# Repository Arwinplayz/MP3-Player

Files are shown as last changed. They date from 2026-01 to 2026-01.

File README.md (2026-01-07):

# Music Player

## After going camping without reception, I though of creating a mp3 music player which runs off a microSD card. It has WiFi and bluetooth compatibility too!

## Project Overview

The goal was to create a way to listen to music without any reception.

---

## Screenshots

### 1. Overall

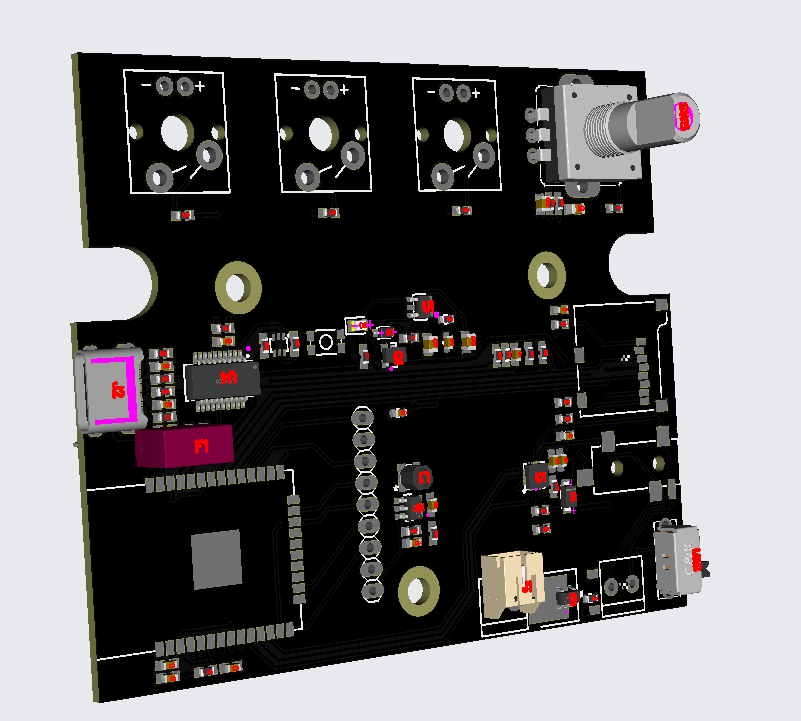
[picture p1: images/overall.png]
Music Player Screenshot


### 2. Schematic

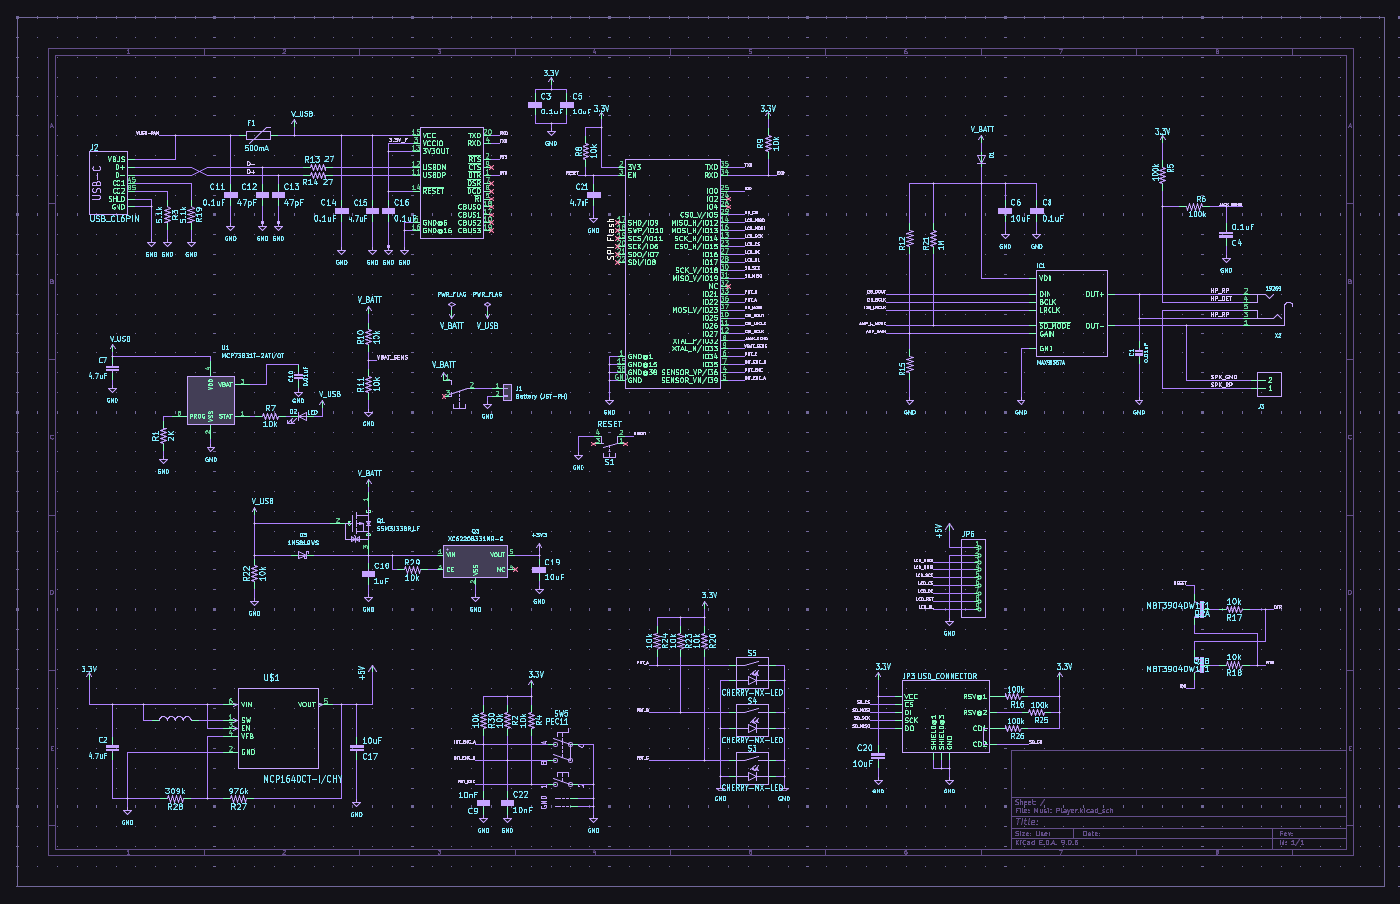
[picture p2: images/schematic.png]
Schematic Screenshot


### 3. PCB layout

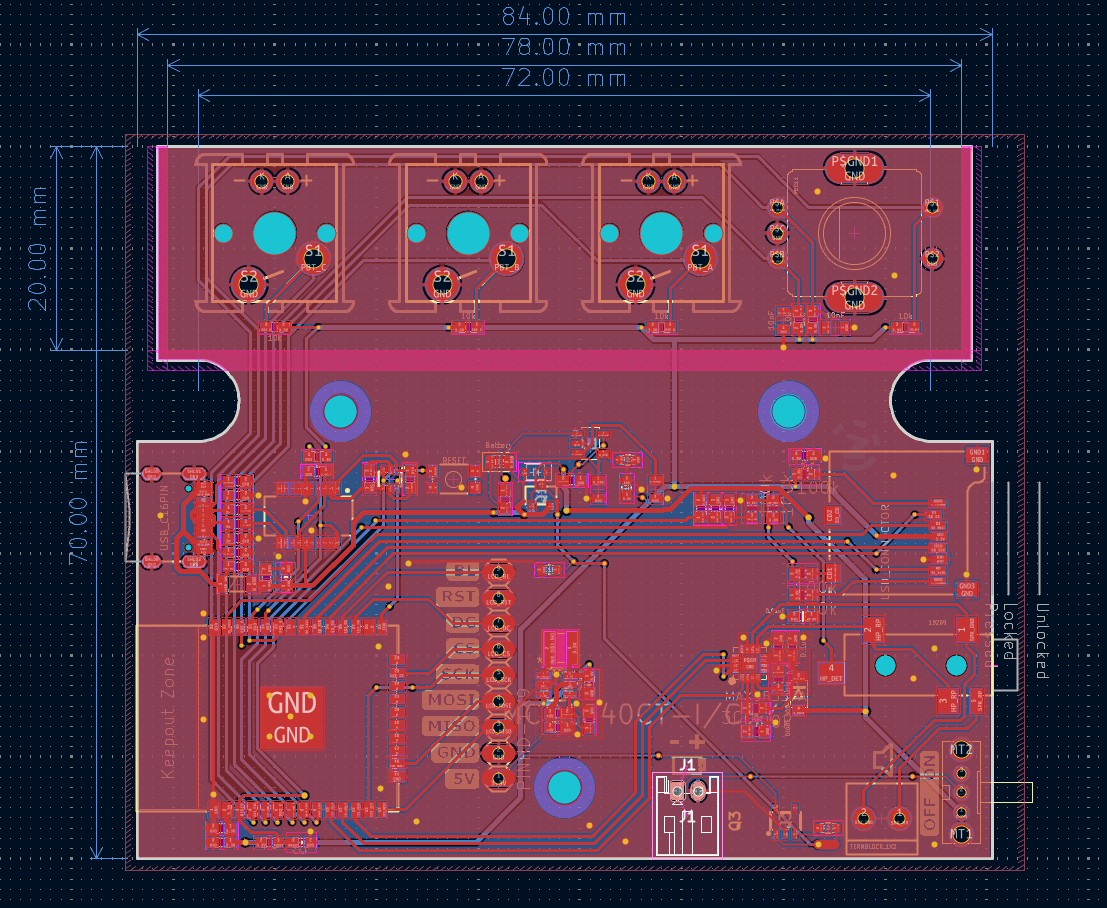
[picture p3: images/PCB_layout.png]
PCB Screenshot


### 4. Design

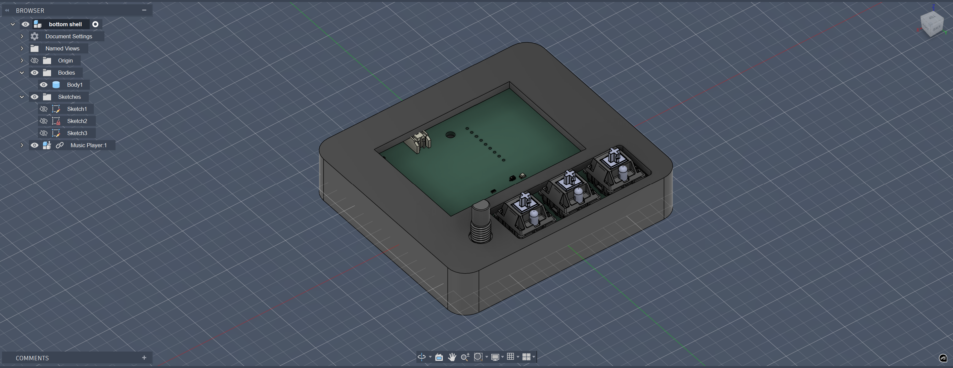
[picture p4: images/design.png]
Design Screenshot


### 5. BOM

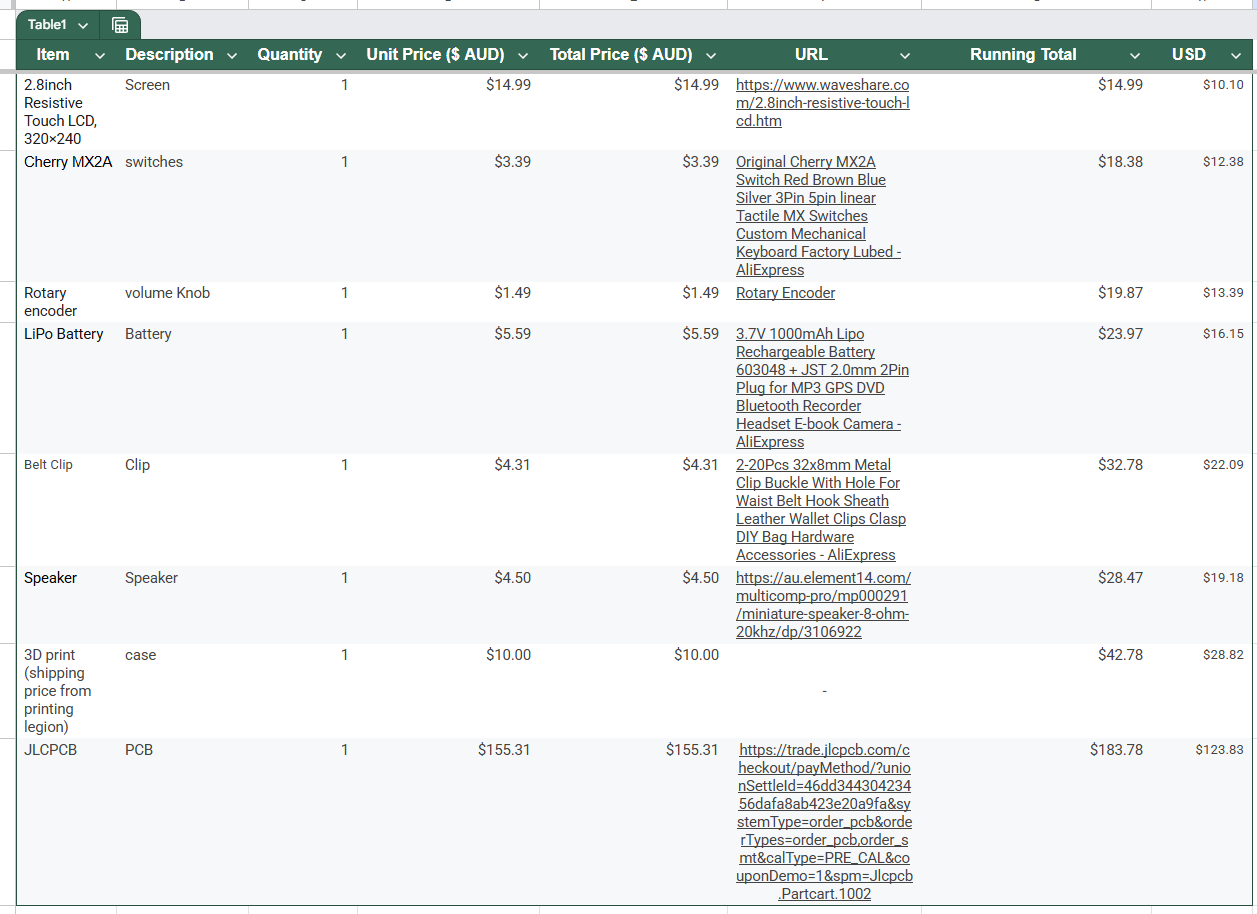
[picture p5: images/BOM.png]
BOM Screenshot


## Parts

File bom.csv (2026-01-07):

Designator | Footprint | Quantity | Value | LCSC Part #
_3, _2, |  | 3
C1 | 0603-NO | 1 | 0.01uF
C10 | 0805 | 1 | 0.01uF
C11, C14, C16, C3, C4, C8 | 0603 | 6 | 0.1uF
C12, C13 | 0603 | 2 | 47pF
C15, C2, C21 | 0603-CAP | 3 | 4.7uF
C17, C19, C20, C5, C6 | 0603 | 5 | 10uF
C18 | 0603 | 1 | 1uF
C22, C9 | 0805 | 2 | 10nF
C7 | 0805 | 1 | 4.7uF
D1 | SOD-123FL | 1 | DIODE_SOD-123FL
D2 | 0805 | 1 | LED
D3 | SOD-323 | 1 | 1N5819WS
F1 | PTC-1206 | 1 | 500mA
IC1 | TQFN-16 | 1 | MAX98357A
J1 | TERMBLOCK_1X2-3.5MM | 1 | Battery (JST-PH)
J2 | USB-C-16P | 1 | USB_C16PIN
J3 | TERMBLOCK_1X2-3.5MM | 1 | TERMBLOCK_1X2
JP3 | MICRO-SD-SOCKET-PP | 1 | USD_CONNECTOR
JP6 | 1X09 | 1 | PINHD-1X9
L1 | WE-TPC_2811_2813_OLD | 1 | 4.7µH
Q1 | SOT23-3 | 1 | SSM3J338R,LF | C146352
Q2 | SC70-6 | 1 | MBT3904DW1T1
Q3 | TO252 | 1 | XC6220B331MR-G | C86534
R1 | 0603 | 1 | 2K
R10, R11, R17, R18, R2, R20, R22, R23, R24, R29, R30, R4, R7, R8, R9 | 0603 | 15 | 10k
R12, R15 | R0603 | 2 | 300k
R13, R14 | 0603 | 2 | 27
R16, R25, R26, R5, R6 | R0603 | 5 | 100k
R19, R3 | 0603 | 2 | 5.1k
R21 | R0603 | 1 | 1M
R27 | 0603 | 1 | 976k
R28 | 0603 | 1 | 309k
S1 | TACTILE_SWITCH_SMD_4.6X2.8MM | 1 | RESET
S3, S4, S5 | CHERRY-MX-LED | 3 | CHERRY-MX-LED
SW1 | OS102011MA1Q | 1 | ~
SW5 | PEC11+SWITCH | 1 | PEC11
U$1 | SOT95P270X145-6N | 1 | MCP1640CT-I/CHY
U1 | SOT-23-5_L3.0-W1.7-P0.95-LS2.8-BR | 1 | MCP73831T-2ATI/OT | C14879
U2 | ESP-WROOM-32 | 1 | ESP-WROOM-32
U4 | SSOP20_L | 1 | FT231XS
X2 | 4UCONN_19269 | 1 | 19269

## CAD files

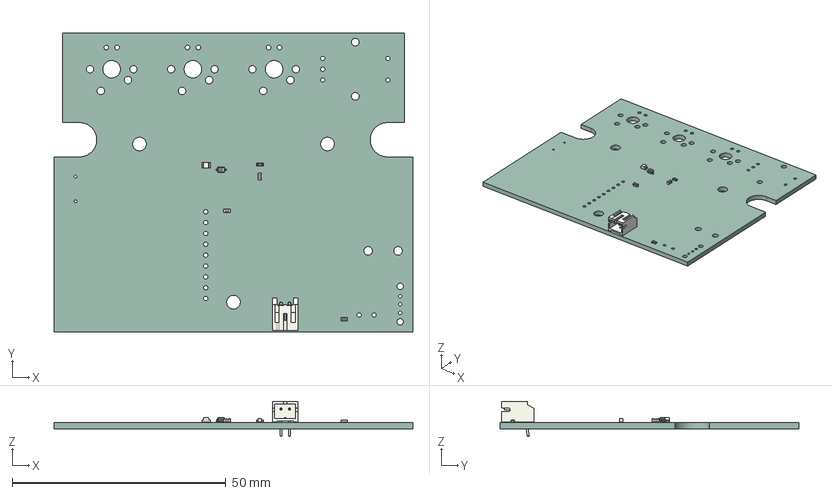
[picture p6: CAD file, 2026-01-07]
CAD/Music Player.step
84.0 x 70.0 x 8.25 mm
C_0603_1608Metric x 2
JST_PH_S2B-PH-K_1x02_P2.00mm_Horizontal
R_0603_1608Metric x 2
D_SOD-323
LED_0805_2012Metric
Music Player_PCB

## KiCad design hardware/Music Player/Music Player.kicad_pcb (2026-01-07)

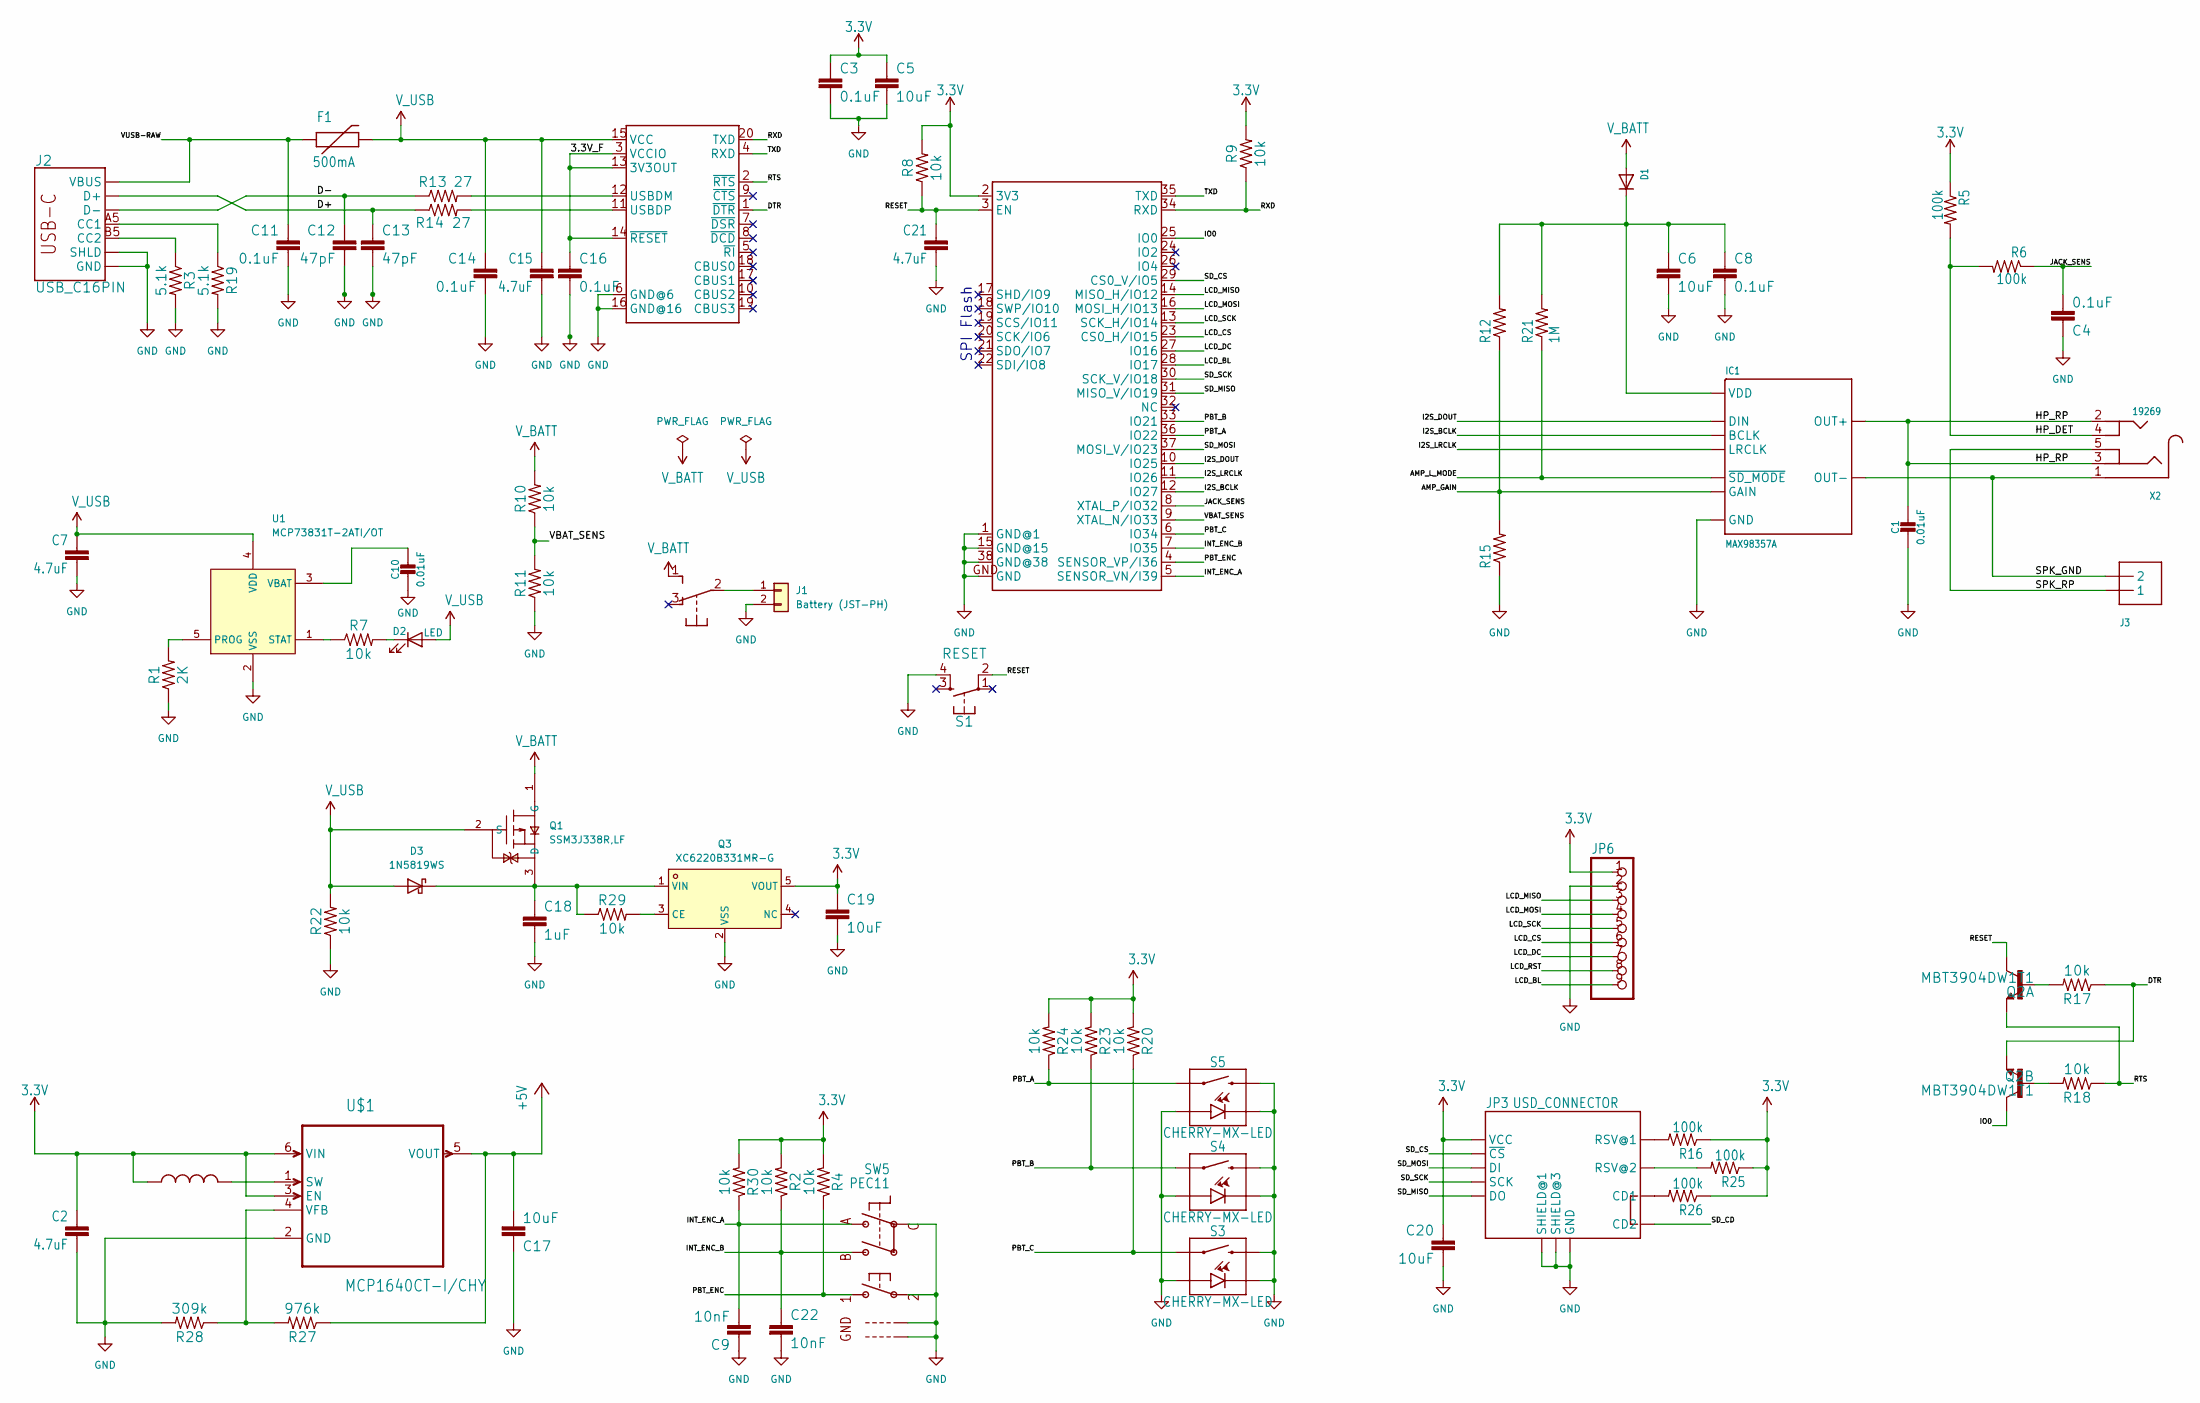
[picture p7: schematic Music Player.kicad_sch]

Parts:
C1, C10: 0.01uF; 0603-NO
C2, C7, C15, C21: 4.7uF; 0603-CAP
C3, C4, C8, C11, C14, C16: 0.1uF; 0603
C5, C6, C17, C20: 10uF; 0603
C9, C22: 10nF; 0805
C12, C13: 47pF; 0603
C18: 1uF; C_0603_1608Metric
C19: 10uF; C_0603_1608Metric
D1: DIODE_SOD-123FL; SOD-123FL
D2: LED; LED_0805_2012Metric
D3: 1N5819WS; D_SOD-323
F1: 500mA; PTC-1206
IC1: MAX98357A; TQFN-16
J1: Battery (JST-PH); JST_PH_S2B-PH-K_1x02_P2.00mm_Horizontal
J2: USB_C16PIN; USB-C-16P
J3: TERMBLOCK_1X2; TERMBLOCK_1X2-3.5MM
JP3: USD_CONNECTOR; MICRO-SD-SOCKET-PP
JP6: PINHD-1X9; 1X09
L1: 4.7µH; WE-TPC_2811_2813_OLD
Q1: SSM3J338R,LF; SOT-23F_L2.9-W1.8-P0.95-LS2.4-BR; LCSC Part C146352
Q2: MBT3904DW1T1; SC70-6
Q3: XC6220B331MR-G; SOT-25_L3.0-W1.6-P0.95-LS2.8-TL; LCSC Part C86534
R1: 2K; 0603
R2, R4, R7, R8, R9, R10, R11, R17, R18, R20, R23, R24, R30: 10k; 0603
R3, R19: 5.1k; 0603
R5, R6, R16, R25, R26: 100k; R0603
R12, R15: 300k; R0603
R13, R14: 27; 0603
R21: 1M; R0603
R22, R29: 10k; R_0603_1608Metric
R27: 976k; 0603
R28: 309k; 0603
S1: RESET; TACTILE_SWITCH_SMD_4.6X2.8MM
S3, S4, S5: CHERRY-MX-LED
SW1: OS102011MA1Q
SW5: PEC11; PEC11+SWITCH
U1: MCP73831T-2ATI/OT; SOT-23-5_L3.0-W1.7-P0.95-LS2.8-BR; LCSC Part C14879
U2: ESP-WROOM-32
U4: FT231XS; SSOP20_L
U$1: MCP1640CT-I/CHY; SOT95P270X145-6N
X2: 19269; 4UCONN_19269

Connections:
3.3V: C2.1, C3.1, C5.1, C19.1, C20.1, JP3.VCC, JP6.1, L1.1, Q3.5 (VOUT), R2.2, R4.2, R5.1, R8.2, R9.2, R16.1, R20.2, R23.2, R24.2, R25.1, R26.1, R30.2, U2.2 (3V3), U$1.3 (EN), U$1.6 (VIN)
+5V: C17.2, R27.1, U$1.5 (VOUT)
/3.3V_F: C16.1, U4.3 (VCCIO), U4.13 (3V3OUT), U4.14 (~RESET)
/AMP_GAIN: IC1.P$2 (GAIN), R12.1, R15.2
/AMP_L_MODE: IC1.P$4 (~SD_MODE), R21.1
/D+: C13.1, J2.A6 (D+), J2.B6 (D+), R14.1
/D-: C12.1, J2.A7 (D-), J2.B7 (D-), R13.1
/DTR: Q2.1 (E), R17.1, U4.1 (~DTR)
/HP_DET: R5.2, R6.2, X2.4
/HP_RP: C1.1, IC1.P$9 (OUT+), X2.2, X2.3
/I2S_BCLK: IC1.P$16 (BCLK), U2.12 (IO27)
/I2S_DOUT: IC1.P$1 (DIN), U2.10 (IO25)
/I2S_LRCLK: IC1.P$14 (LRCLK), U2.11 (IO26)
/INT_ENC_A: C9.2, R30.1, SW5.P$A, U2.5 (SENSOR_VN/I39)
/INT_ENC_B: C22.1, R2.1, SW5.P$B, U2.7 (IO35)
/IO0: Q2.6 (C), U2.25 (IO0)
/JACK_SENS: C4.2, R6.1, U2.8 (XTAL_P/IO32)
/LCD_BL: JP6.9, U2.28 (IO17)
/LCD_CS: JP6.6, U2.23 (CS0_H/IO15)
/LCD_DC: JP6.7, U2.27 (IO16)
/LCD_MISO: JP6.3, U2.14 (MISO_H/IO12)
/LCD_MOSI: JP6.4, U2.16 (MOSI_H/IO13)
/LCD_RST: JP6.8
/LCD_SCK: JP6.5, U2.13 (SCK_H/IO14)
/PBT_A: R24.1, S5.S1, U2.36 (IO22)
/PBT_B: R23.1, S4.S1, U2.33 (IO21)
/PBT_C: R20.1, S3.S1, U2.6 (IO34)
/PBT_ENC: R4.1, SW5.P$1, U2.4 (SENSOR_VP/I36)
/RESET: C21.1, Q2.3 (C), R8.1, S1.2, U2.3 (EN)
/RTS: Q2.4 (E), R18.1, U4.2 (~RTS)
/RXD: R9.1, U2.34 (RXD), U4.20 (TXD)
/SD_CD: JP3.CD2
/SD_CS: JP3.CS (~CS), U2.29 (CS0_V/IO5)
/SD_MISO: JP3.DO, U2.31 (MISO_V/IO19)
/SD_MOSI: JP3.DI, U2.37 (MOSI_V/IO23)
/SD_SCK: JP3.SCLK (SCK), U2.30 (SCK_V/IO18)
/SPK_GND: IC1.P$10 (OUT-), J3.2, X2.1
/SPK_RP: J3.1, X2.5
/TXD: U2.35 (TXD), U4.4 (RXD)
/VBAT_SENS: R10.1, R11.2, U2.9 (XTAL_N/IO33)
/VUSB-RAW: C11.1, F1.1, J2.VBUS1 (VBUS), J2.VBUS2 (VBUS)
GND: C1.2, C2.2, C3.2, C4.1, C5.2, C6.2, C7.2, C8.2, C9.1, C10.2, C11.2, C12.2, C13.2, C14.2, C15.2, C16.2, C17.1, C18.2, C19.2, C20.2, C21.2, C22.2, IC1.P$3 (GND), IC1.P$11 (GND), IC1.P$15 (GND), IC1.P$EP (GND), J1.2, J2.GND, J2.GND2 (GND), J2.SHLD1 (SHLD), J2.SHLD2 (SHLD), J2.SHLD3 (SHLD), J2.SHLD4 (SHLD), J2.SHLD5 (SHLD), J2.SHLD6 (SHLD), J2.SHLD7 (SHLD), J2.SHLD8 (SHLD), JP3.GND, JP3.GND1 (SHIELD@1), JP3.GND3 (SHIELD@3), JP6.2, Q3.2 (VSS), R1.1, R3.2, R11.1, R15.1, R19.2, R22.1, R28.2, S1.4, S3.A, S3.K (C), S3.S2, S4.A, S4.K (C), S4.S2, S5.A, S5.K (C), S5.S2, SW5.P$2, SW5.P$C, SW5.P$GND1, SW5.P$GND2, U1.2 (VSS), U2.1 (GND@1), U2.15 (GND@15), U2.38 (GND@38), U2.GND, U4.6 (GND@6), U4.16 (GND@16), U$1.2 (GND)
unnamed: C6.1, C8.1, D1.C, IC1.P$7 (VDD), IC1.P$8 (VDD), R12.2, R21.2
unnamed: D2.1 (K), R7.2
unnamed: C18.1, D3.1 (K), Q1.3 (D), Q3.1 (VIN), R29.1
unnamed: J1.1, SW1.2
unnamed: J2.A5 (CC1), R19.1
unnamed: J2.B5 (CC2), R3.1
unnamed: JP3.CD1, R26.2
unnamed: JP3.RSV1 (RSV@1), R16.2
unnamed: JP3.RSV2 (RSV@2), R25.2
unnamed: Q2.5 (B), R17.2
unnamed: Q2.2 (B), R18.2
unnamed: Q3.3 (CE), R29.2
unnamed: R1.2, U1.5 (PROG)
unnamed: R7.1, U1.1 (STAT)
unnamed: C10.1, U1.3 (VBAT)
unnamed: R13.2, U4.12 (USBDM)
unnamed: R14.2, U4.11 (USBDP)
unnamed: L1.2, U$1.1 (SW)
unnamed: R27.2, R28.1, U$1.4 (VFB)
V_BATT: D1.A, Q1.1 (G), R10.2, SW1.1 (S)
V_USB: C7.1, C14.1, C15.1, D2.2 (A), D3.2 (A), F1.2, Q1.2 (S), R22.2, U1.4 (VDD), U4.15 (VCC)

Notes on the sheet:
SPI Flash

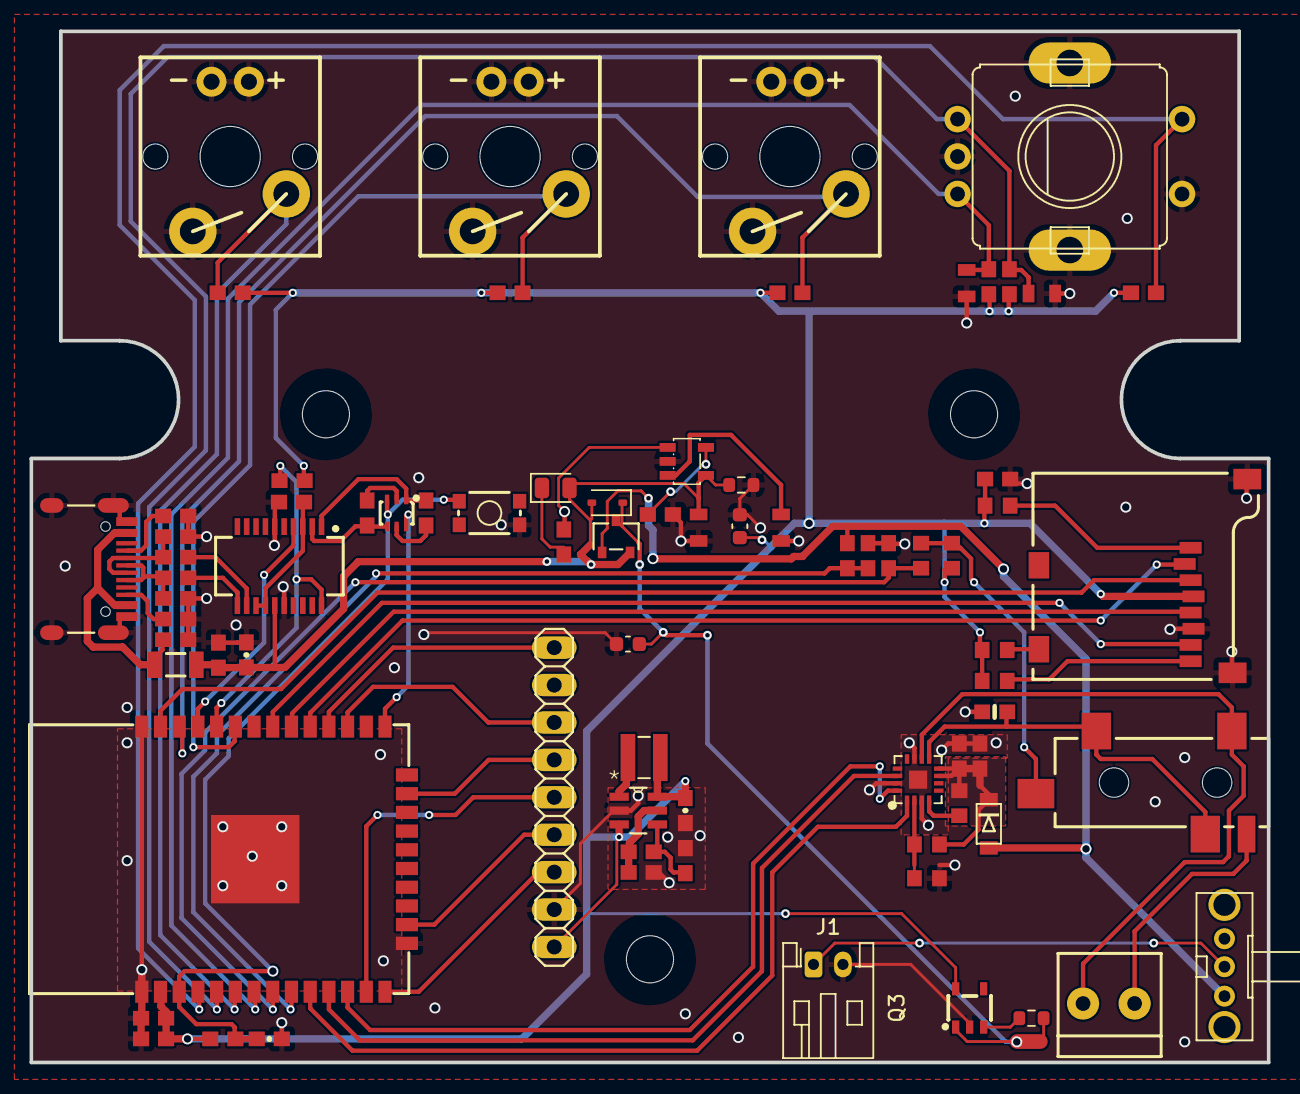
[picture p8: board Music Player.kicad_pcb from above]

Board: 2 copper layers, 84.0 x 70.0 mm, 77 parts (0 on the bottom side), 61 nets.

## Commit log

2026-01-07 added local files
    [Music Player.kicad_pcb, Music Player.kicad_sch, Music Player.step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]
2026-01-20 moved BOM to root
    [bom.csv]
